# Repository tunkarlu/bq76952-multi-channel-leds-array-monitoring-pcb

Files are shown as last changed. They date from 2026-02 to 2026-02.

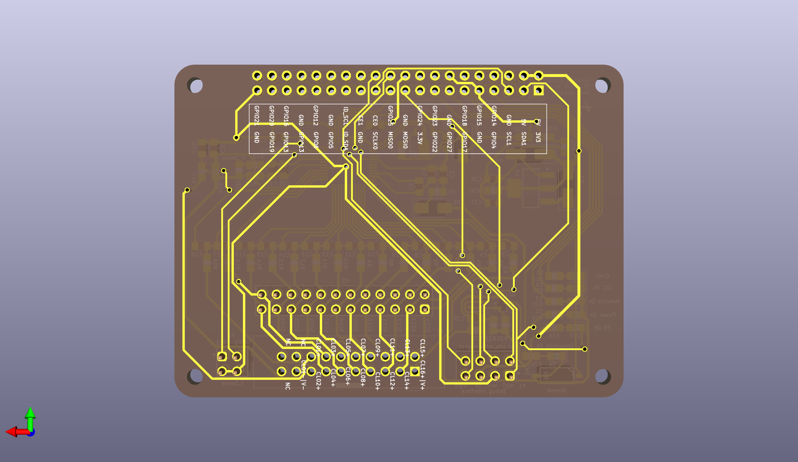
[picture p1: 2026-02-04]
snapshots/BQ76952_uPi_Hat_Bottom.png

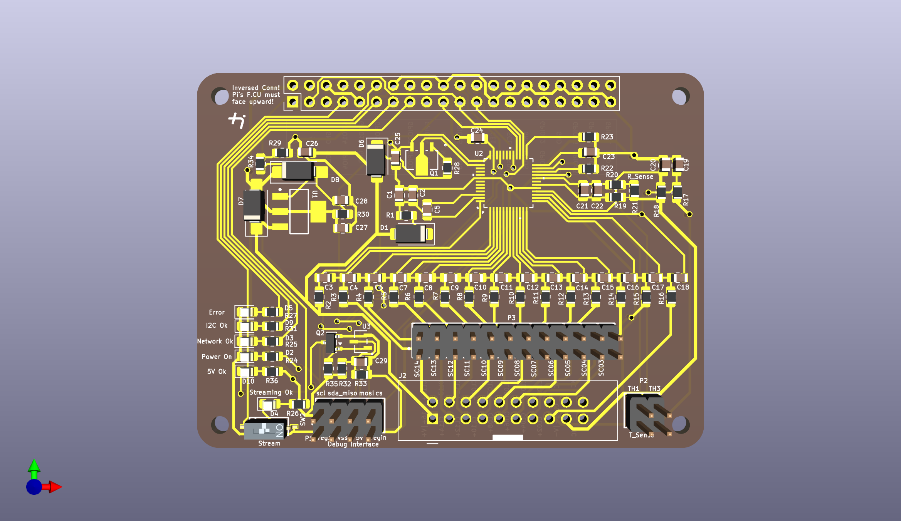
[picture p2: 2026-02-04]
snapshots/BQ76952_uPi_Hat_Top.png

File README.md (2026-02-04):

# BQ76952 Multi-Channel LED Monitoring PCB

## How to Use This Repo
1. Clone or download the project and open `BQ76952_uPi_Hat.kicad_pro` with KiCad 8.x or newer.
2. Use the schematic (`.kicad_sch`) to inspect signal naming, channel scaling, and LM317 regulator settings; propagate changes into the PCB (`.kicad_pcb`) via KiCad's **Update PCB from Schematic** tool.
3. Generate fabrication outputs (Gerbers, drills, pick-and-place, and `BQ76952_uPi_Hat.csv`) when you are ready to order boards or run simulations for your experiments.
4. Document measurement runs and firmware configurations in your own branch to keep bachelor thesis logs aligned with the exact hardware revision.
BQ76952_uPi_Hat_Filled_Top

## Purpose & Scope
This board is the hardware platform for a bachelor thesis focused on predicting high-power LED lifetime and scheduling preventative maintenance. It leverages Texas Instruments' `BQ76952` BMS front-end to acquire per-LED telemetry with up to 32-bit resolution, enabling precise degradation tracking for as many as 16 LEDs (down to 5 by shorting unused inputs). The design is intentionally scalable: multiple boards can share a single Raspberry Pi Zero host via SPI chip-select fan-out or operate independently over I2C.

## Hardware Highlights
- `BQ76952` monitors every LED string, providing ADC accuracy, protection, and internal diagnostics normally reserved for battery stacks.
- External LM317-based LDO supplies the Raspberry Pi Zero directly from the board; an additional comparator supervises the LDO output so a 5 V status indicator confirms the Pi rail is within tolerance.
- Status LEDs expose board health at a glance: chip power-on via the internal LDO, network OK, I2C OK, streaming OK, error flags, and 5 V OK from the comparator stage.
- 2.54 mm pitch Würth 20-pin connector handles the LED array interface with ample current capability and clear pin-1 orientation for field swaps.
- Mini DIP switch enables or disables immediate cloud streaming so field techs can start data uploads without reflashing firmware.
- Debug header breaks out key BQ76952 and Pi Zero signals to simplify firmware bring-up and probing.

## File Structure (Essential Only)
- `BQ76952_uPi_Hat.kicad_pro` – master KiCad project tying schematic, PCB, and fabrication settings together.
- `BQ76952_uPi_Hat.kicad_sch` – complete schematic including LED channels, LM317 LDO, comparator, DIP switch, and interface headers.
- `BQ76952_uPi_Hat.kicad_pcb` – board layout optimized for short sense paths and high-current connector routing.
- `BQ76952_uPi_Hat.csv` – bill of materials exported for sourcing and documentation.
- `BQ76952_uPi_Hat-backups/` – automatically generated KiCad backup snapshots for traceability between thesis milestones.

## Operating Modes & Scalability
- **LED Capacity**: Populate between 5 and 16 channels; unused inputs can be shorted to maintain ADC scaling without redesigning the board.
- **Host Interfaces**: Default communication relies on I2C, but SPI pads and separate slave-select lines allow one microprocessor to orchestrate two boards simultaneously.
- **Streaming Control**: Flip the dedicated DIP switch to trigger the firmware's cloud-streaming routine, useful when demonstrating predictive maintenance dashboards.
- **Resolution**: Each LED measurement path maintains up to 32 bits of resolution through firmware-side accumulation, helping extrapolate lumen depreciation trends.

## Bring-Up & Test Flow
1. Power the board from a current-limited supply, verify the BQ76952 internal LDO brings up the power-on indicator, and ensure the comparator asserts 5 V OK once the LM317 output settles.
2. Attach a Raspberry Pi Zero through the onboard connector, confirm I2C communication, then enable SPI if you plan to chain boards via different slave-select pins.
3. Toggle the DIP switch to start cloud streaming and observe the network and streaming indicators before connecting real LED loads.
4. Connect LED strings incrementally, watching each status LED and reading diagnostic registers to confirm per-channel integrity.
5. Use the debug header to probe GPIOs or update firmware while recording data for the thesis lifetime-prediction models.

## Thesis Context
The design forms the experimental backbone for a bachelor thesis investigating predictive maintenance of high-power LED arrays. It demonstrates how a BMS-grade analog front-end, auxiliary regulation, and human-friendly status cues can be repurposed into a scalable monitoring platform suitable for lab studies and eventual field deployments.

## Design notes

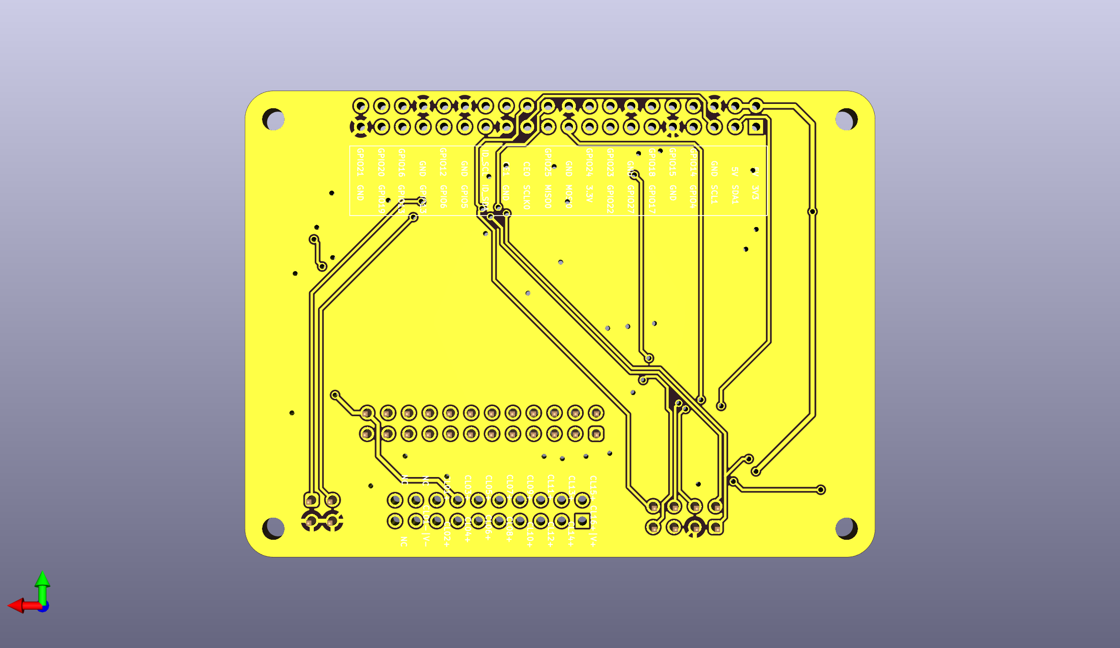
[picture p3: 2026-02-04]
snapshots/BQ76952_uPi_Hat_Filled_Bottom.png

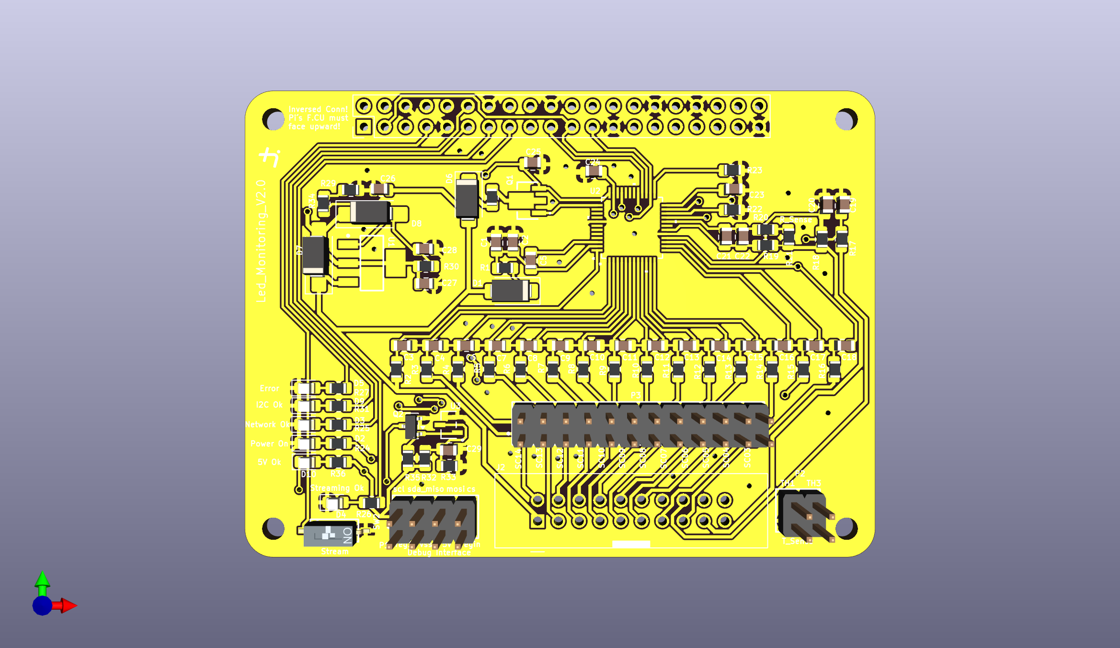
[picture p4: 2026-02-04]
snapshots/BQ76952_uPi_Hat_Filled_Top.png

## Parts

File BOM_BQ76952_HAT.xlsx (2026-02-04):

Main Board
Reference | Value | Datasheet | Footprint | Qty | DNP | Manufacturer Part Number | Manufacturer_Name
C1,C24,C27 | 1uF | ~ | Capacitor_SMD:C_0805_2012Metric,Capacitor_SMD:C_0805_2012Metric_Pad1.18x1.45mm_HandSolder | 3
C2,C21 | 100pF | ~ | Capacitor_SMD:C_0805_2012Metric_Pad1.18x1.45mm_HandSolder | 2
C3,C4,C6,C7,C8,C9,C10,C11,C12,C13,C14,C15,C16,C17,C18,C19,C20 | 220nF | ~ | Capacitor_SMD:C_0805_2012Metric_Pad1.18x1.45mm_HandSolder | 17
C5 | 0.47uF | ~ | Capacitor_SMD:C_0805_2012Metric_Pad1.18x1.45mm_HandSolder | 1
C22,C26 | 0.1uF | ~ | Capacitor_SMD:C_0805_2012Metric,Capacitor_SMD:C_0805_2012Metric_Pad1.18x1.45mm_HandSolder | 2
C23 | 2.2uF | ~ | Capacitor_SMD:C_0805_2012Metric_Pad1.18x1.45mm_HandSolder | 1
C25 | 22nF | ~ | Capacitor_SMD:C_0805_2012Metric_Pad1.18x1.45mm_HandSolder | 1
C28 | 10uF | ~ | Capacitor_SMD:C_0805_2012Metric_Pad1.18x1.45mm_HandSolder | 1
C29 | 100nF | ~ | Capacitor_SMD:C_0805_2012Metric_Pad1.18x1.45mm_HandSolder | 1
D1,D6 | 100V | ~ | Diode_SMD:D_SMA | 2
D2,D3,D4,D5,D9,D10 | LED | ~ | LED_SMD:LED_0805_2012Metric_Pad1.15x1.40mm_HandSolder | 6
D7,D8 | 1N4002 | http://www.vishay.com/docs/88503/1n4001.pdf | Diode_SMD:D_SMA_Handsoldering | 2
J1 | GPIO | ~ | Inverted_PinSocket:PinSocket_2x20_P2.54mm_Vertical_Inverted | 1 |  | 61304021821 | Würth Electronic
J2 | 61202021621 | https://www.we-online.com/en/components/products/datasheet/61202021621?ki | Connector_THT_Würth_BHD:J_Wurth_WR-BHD_61202021621 | 1 |  | 61202021621 | Würth Electronic
P1 | 61300821121 |  | WR_PHD Dual Male:61300821121 | 1 |  | 61300821121 | Würth Electronic
P2 | 61300421121 |  | WR_PHD Dual Male:61300421121 | 1 |  | 61300421121 | Würth Electronic
P3 | 61302421121 |  | WR_PHD Dual Male:61302421121 | 1 |  | 61302421121 | Würth Electronic
Q1 | NPN | https://ngspice.sourceforge.io/docs/ngspice-html-manual/manual.xhtml#cha_BJTs | FCX495TA:SOT89_DIO | 1 |  | FCX495TA
Q2 | 2N7002 | https://www.onsemi.com/pub/Collateral/NDS7002A-D.PDF | Package_TO_SOT_SMD:SOT-23 | 1 |  | 2N7002 | Onsemi
R1,R19,R20 | 100 | ~ | Resistor_SMD:R_0805_2012Metric_Pad1.20x1.40mm_HandSolder | 3
R2,R3,R4,R5,R6,R7,R8,R9,R10,R11,R12,R13,R14,R15,R16,R17,R18 | 20 | ~ | Resistor_SMD:R_0805_2012Metric_Pad1.20x1.40mm_HandSolder | 17
R21 | 0.001 | ~ | Resistor_SMD:R_0805_2012Metric_Pad1.20x1.40mm_HandSolder | 1
R22,R33,R35 | 10k | ~ | Resistor_SMD:R_0805_2012Metric_Pad1.20x1.40mm_HandSolder | 3
R23 | 1k | ~ | Resistor_SMD:R_0805_2012Metric_Pad1.20x1.40mm_HandSolder | 1
R24,R25,R26,R27,R31,R36 | R | ~ | Resistor_SMD:R_0805_2012Metric_Pad1.20x1.40mm_HandSolder | 6
R28 | 300 | ~ | Resistor_SMD:R_0805_2012Metric_Pad1.20x1.40mm_HandSolder | 1
R29 | 680 | ~ | Resistor_SMD:R_0805_2012Metric_Pad1.20x1.40mm_HandSolder | 1
R30 | 240 | ~ | Resistor_SMD:R_0805_2012Metric_Pad1.20x1.40mm_HandSolder | 1
R32 | 1.5k | ~ | Resistor_SMD:R_0805_2012Metric_Pad1.20x1.40mm_HandSolder | 1
R34 | 33 | ~ | Resistor_SMD:R_0805_2012Metric_Pad1.20x1.40mm_HandSolder | 1
SW2 | 416131160801 | ~ | WS-DISV:416131160801 | 1 |  | 416131160801 | Würth Electronic
U1 | LM317DCY | https://www.ti.com/lit/gpn/lm317 | LM317DCY:DCY0004A_N | 1 |  | LM317DCY | TI
U2 | PBQ76952PFBT | https://www.ti.com/lit/gpn/bq76952 | BQ769x2:PFB48_TEX | 1 |  | BQ76952 | TI
U3 | STM1061N38WX6F | https://www.st.com/resource/en/datasheet/stm1061.pdf | STM1061N38WX6F:SOT-23_STM | 1 |  | STM1061N38WX6F | ST
Mating Connector
Pi Pin Header |  |  |  | 1 |  | 61304021121 | Würth Electronic
WE BHD 20 pins cable side |  |  |  | 2 |  | 61202023021 | Würth Electronic
Ribbon cable 20 pins |  |  |  | 1 |  | 63912015521 or 63912015521CAB | Würth Electronic
Breakout Board
Reference | Qty | Value | DNP | Exclude from BOM | Exclude from Board | Footprint | Datasheet | Manufacturer_Name | Manufacturer_Part_Number
J1,J3 | 2 | 61202021621 |  |  |  | Connector_THT_Würth_BHD:J_Wurth_WR-BHD_61202021621 | https://www.we-online.com/en/components/products/datasheet/61202021621?ki | Würth Electronic | 61202021621
J2,J4,J5,J6,J7,J8,J9,J10 | 8 | 20021321-00006C4LF |  |  |  | Amphenol:2002132100006C4LF | https://cdn.amphenol-cs.com/media/wysiwyg/files/documentation/datasheet/boardwiretoboard/bwb_minitek127_btb.pdf | Amphenol Communications Solutions | 20021321-00006C4LF

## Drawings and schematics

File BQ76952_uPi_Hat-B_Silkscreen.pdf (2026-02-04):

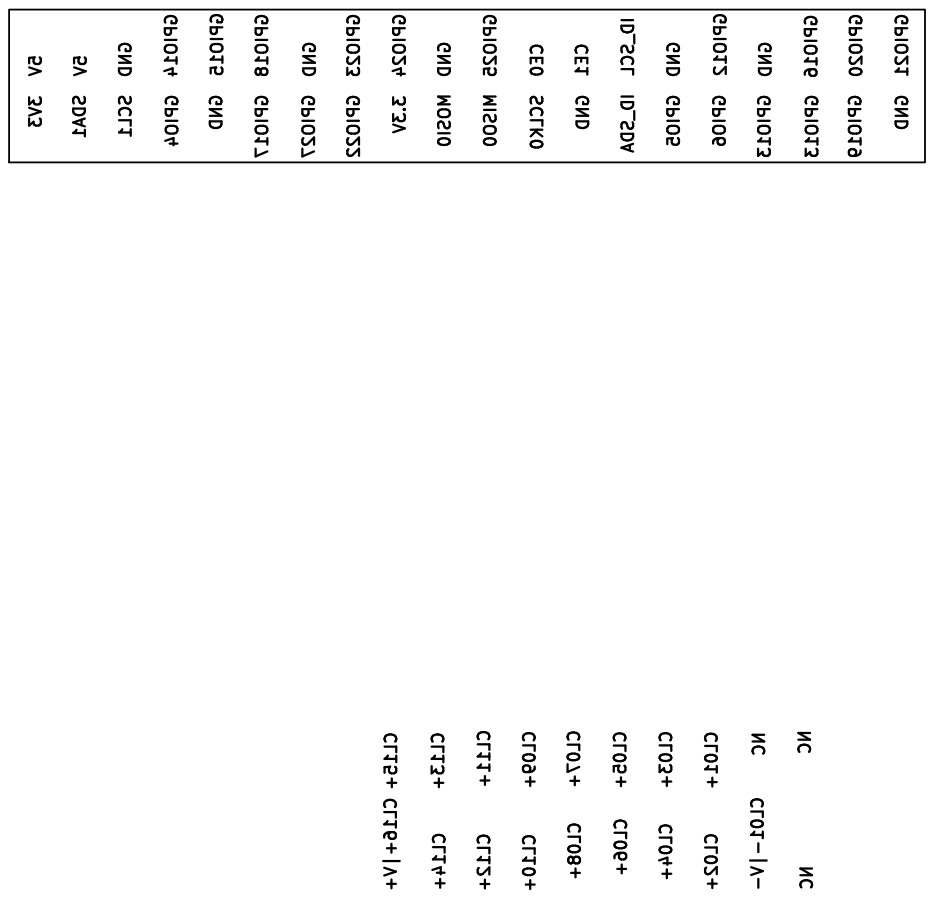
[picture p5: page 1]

CL03+ NC NC CL02+ CL16+|V+ CL01-|V- CL07+ CL14+ CL12+ CL15+ CL09+ CL06+ CL11+ NC CL10+ CL05+ CL08+ CL04+ CL13+ CL01+ SDA1 SCL1 GPIO22 3.3V MOSI0 MISO0 GPIO5 GPIO18 GPIO23 GPIO25 ID_SCL GPIO20 3V3 GND GPIO165V ID_SDA CE0 GPIO13 GPIO19 GPIO12 GPIO27 GND GPIO14 GPIO21 GPIO4 SCLK0 GND CE1 GND GPIO17 GPIO6 5V GND GPIO15 GPIO24 GPIO13 GND GND GND

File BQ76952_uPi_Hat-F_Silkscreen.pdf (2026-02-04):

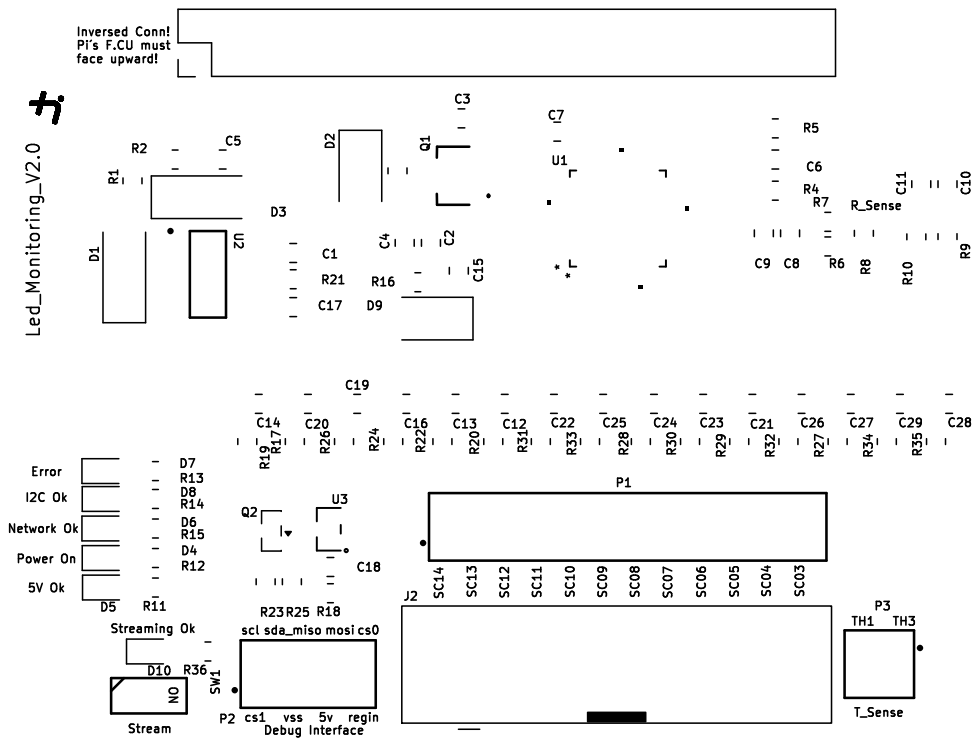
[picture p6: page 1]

Inversed Conn! þÿPi´s F.CU must
face upward! Led_Monitoring_V2.0

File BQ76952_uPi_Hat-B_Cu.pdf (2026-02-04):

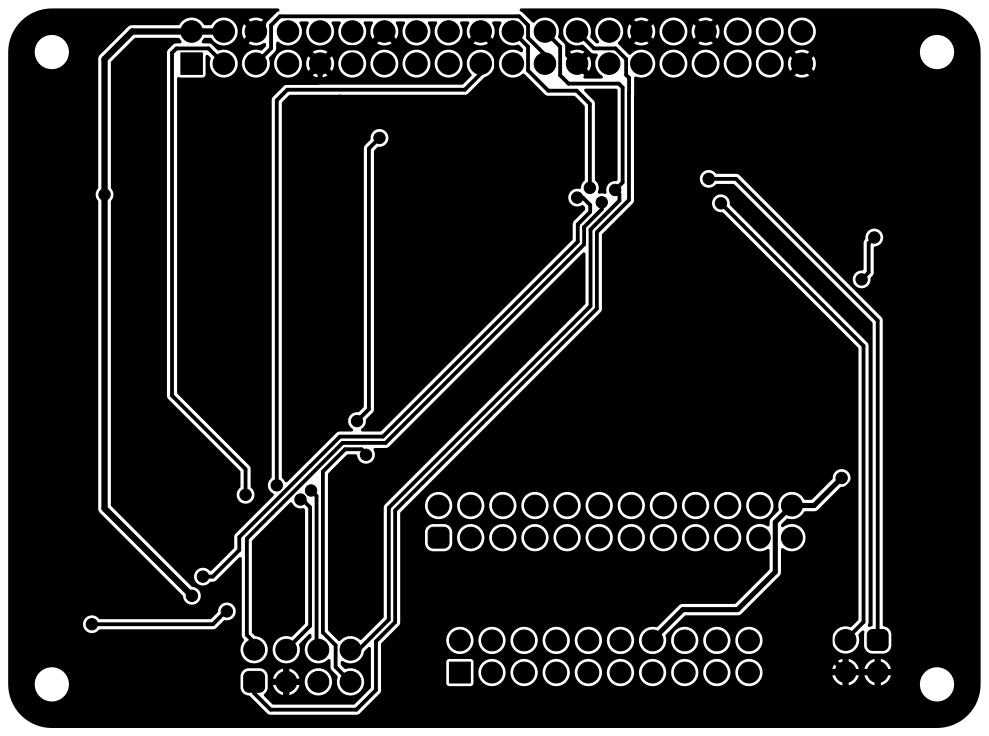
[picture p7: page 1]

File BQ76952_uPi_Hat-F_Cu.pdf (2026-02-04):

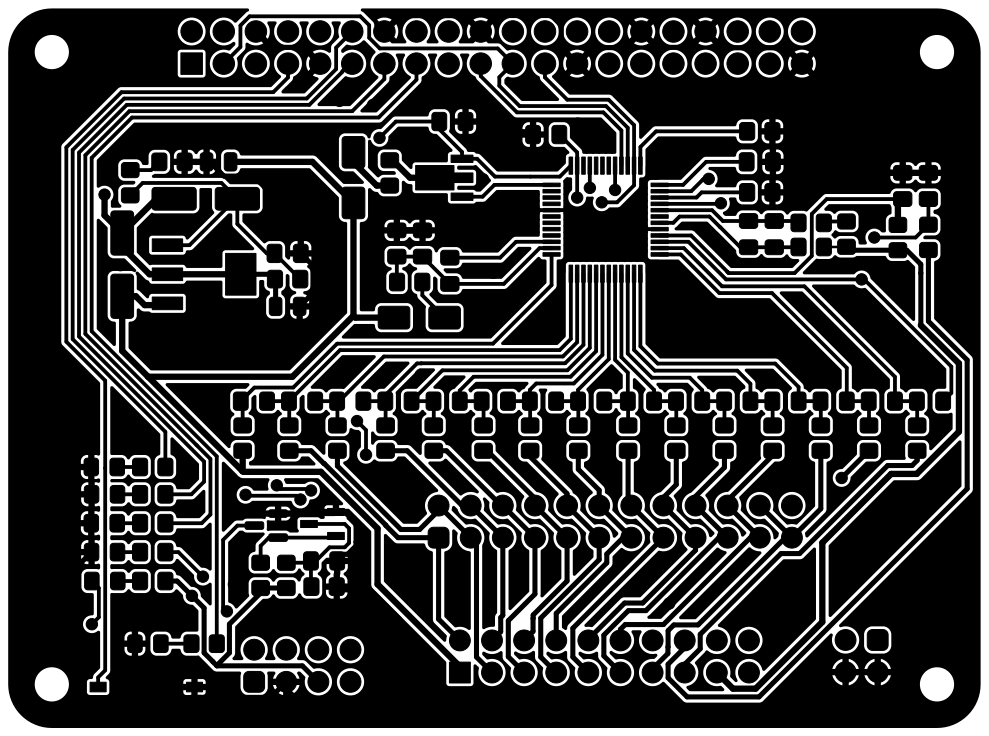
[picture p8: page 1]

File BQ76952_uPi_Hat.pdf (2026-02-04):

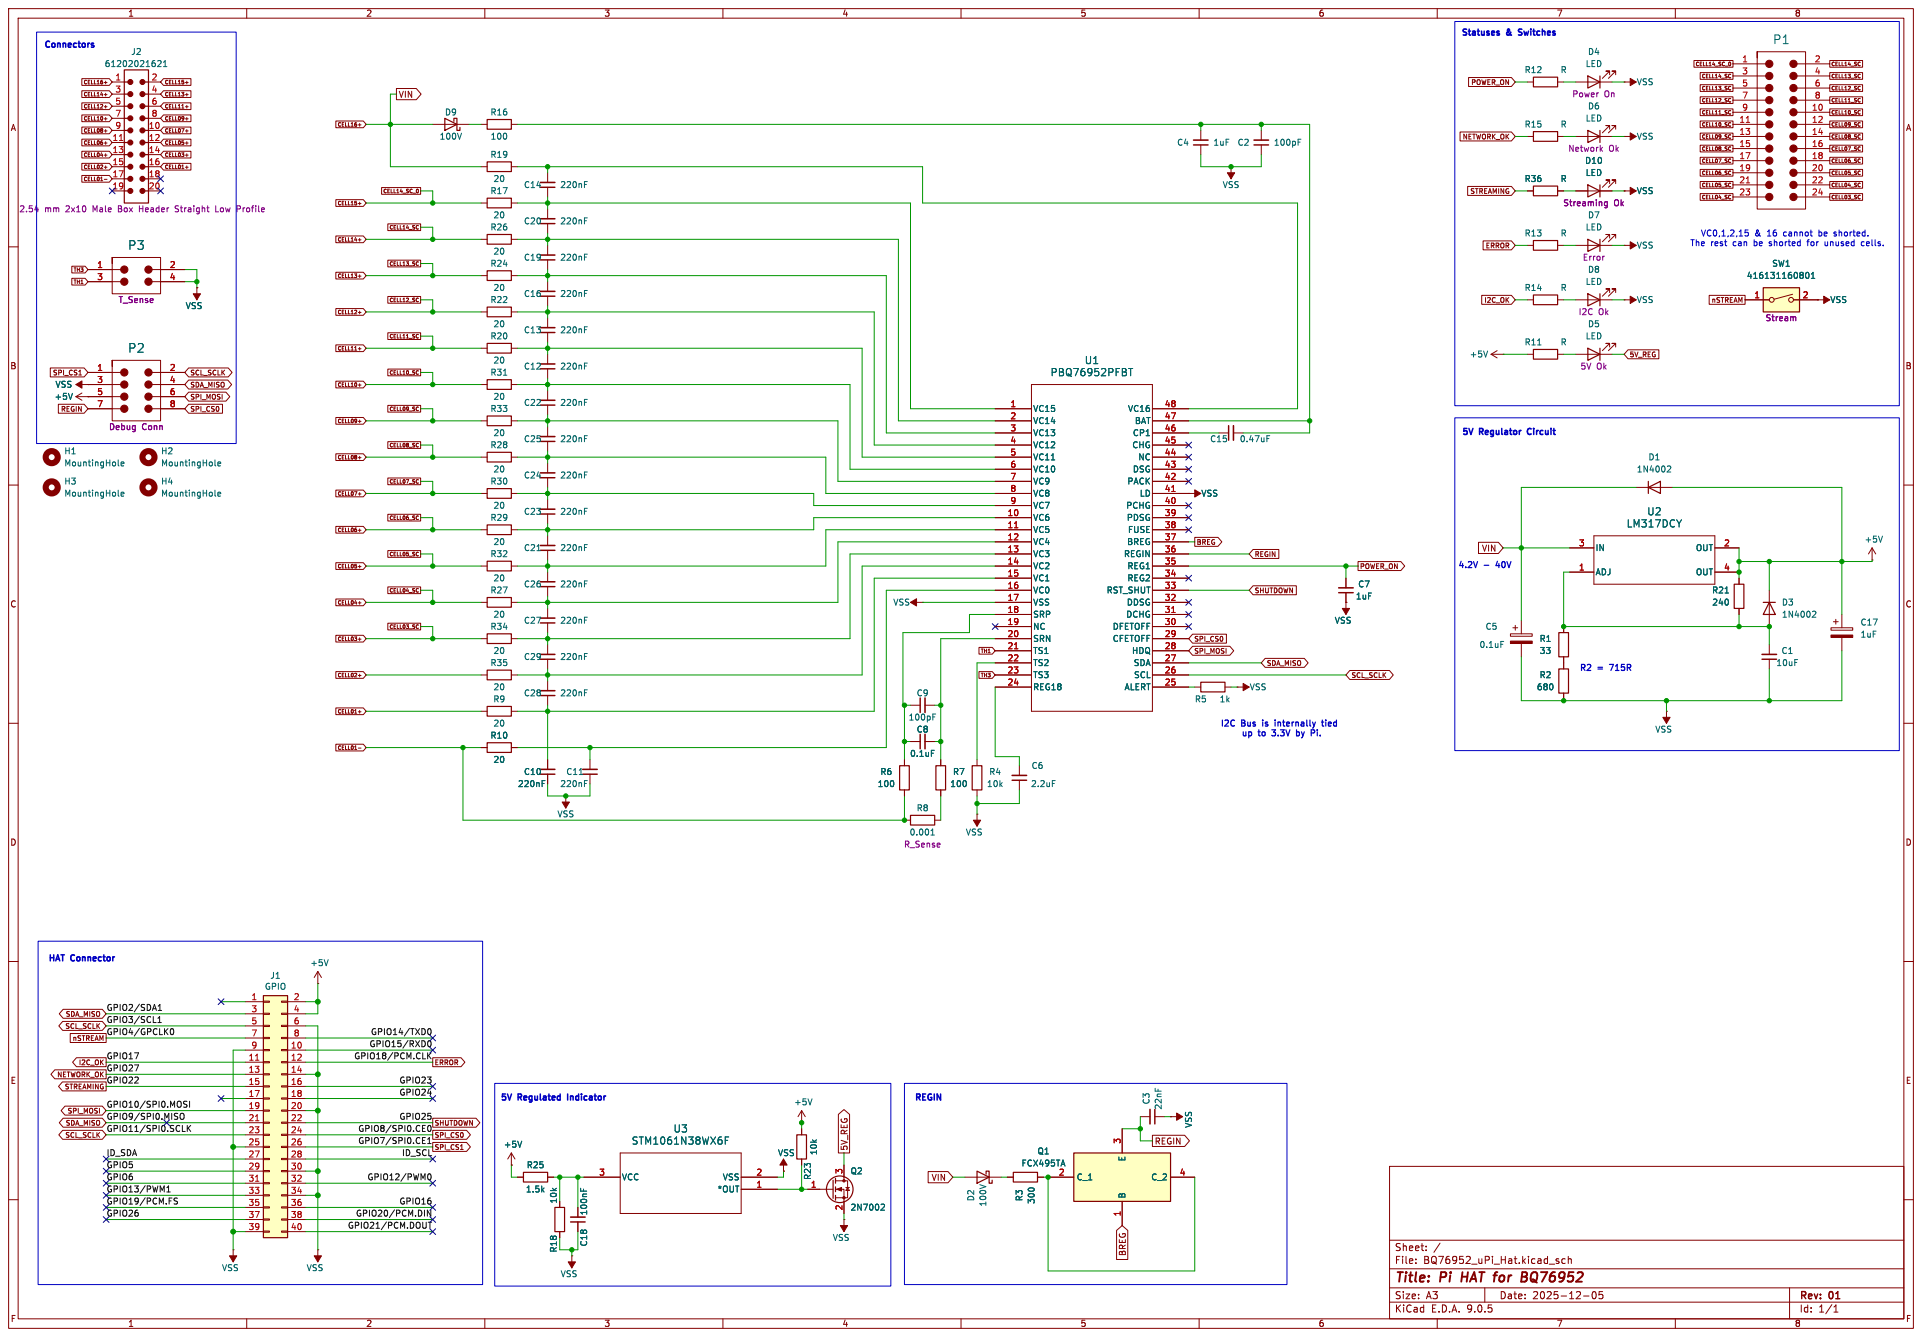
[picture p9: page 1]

Id: 1/1 Title: Pi HAT for BQ76952

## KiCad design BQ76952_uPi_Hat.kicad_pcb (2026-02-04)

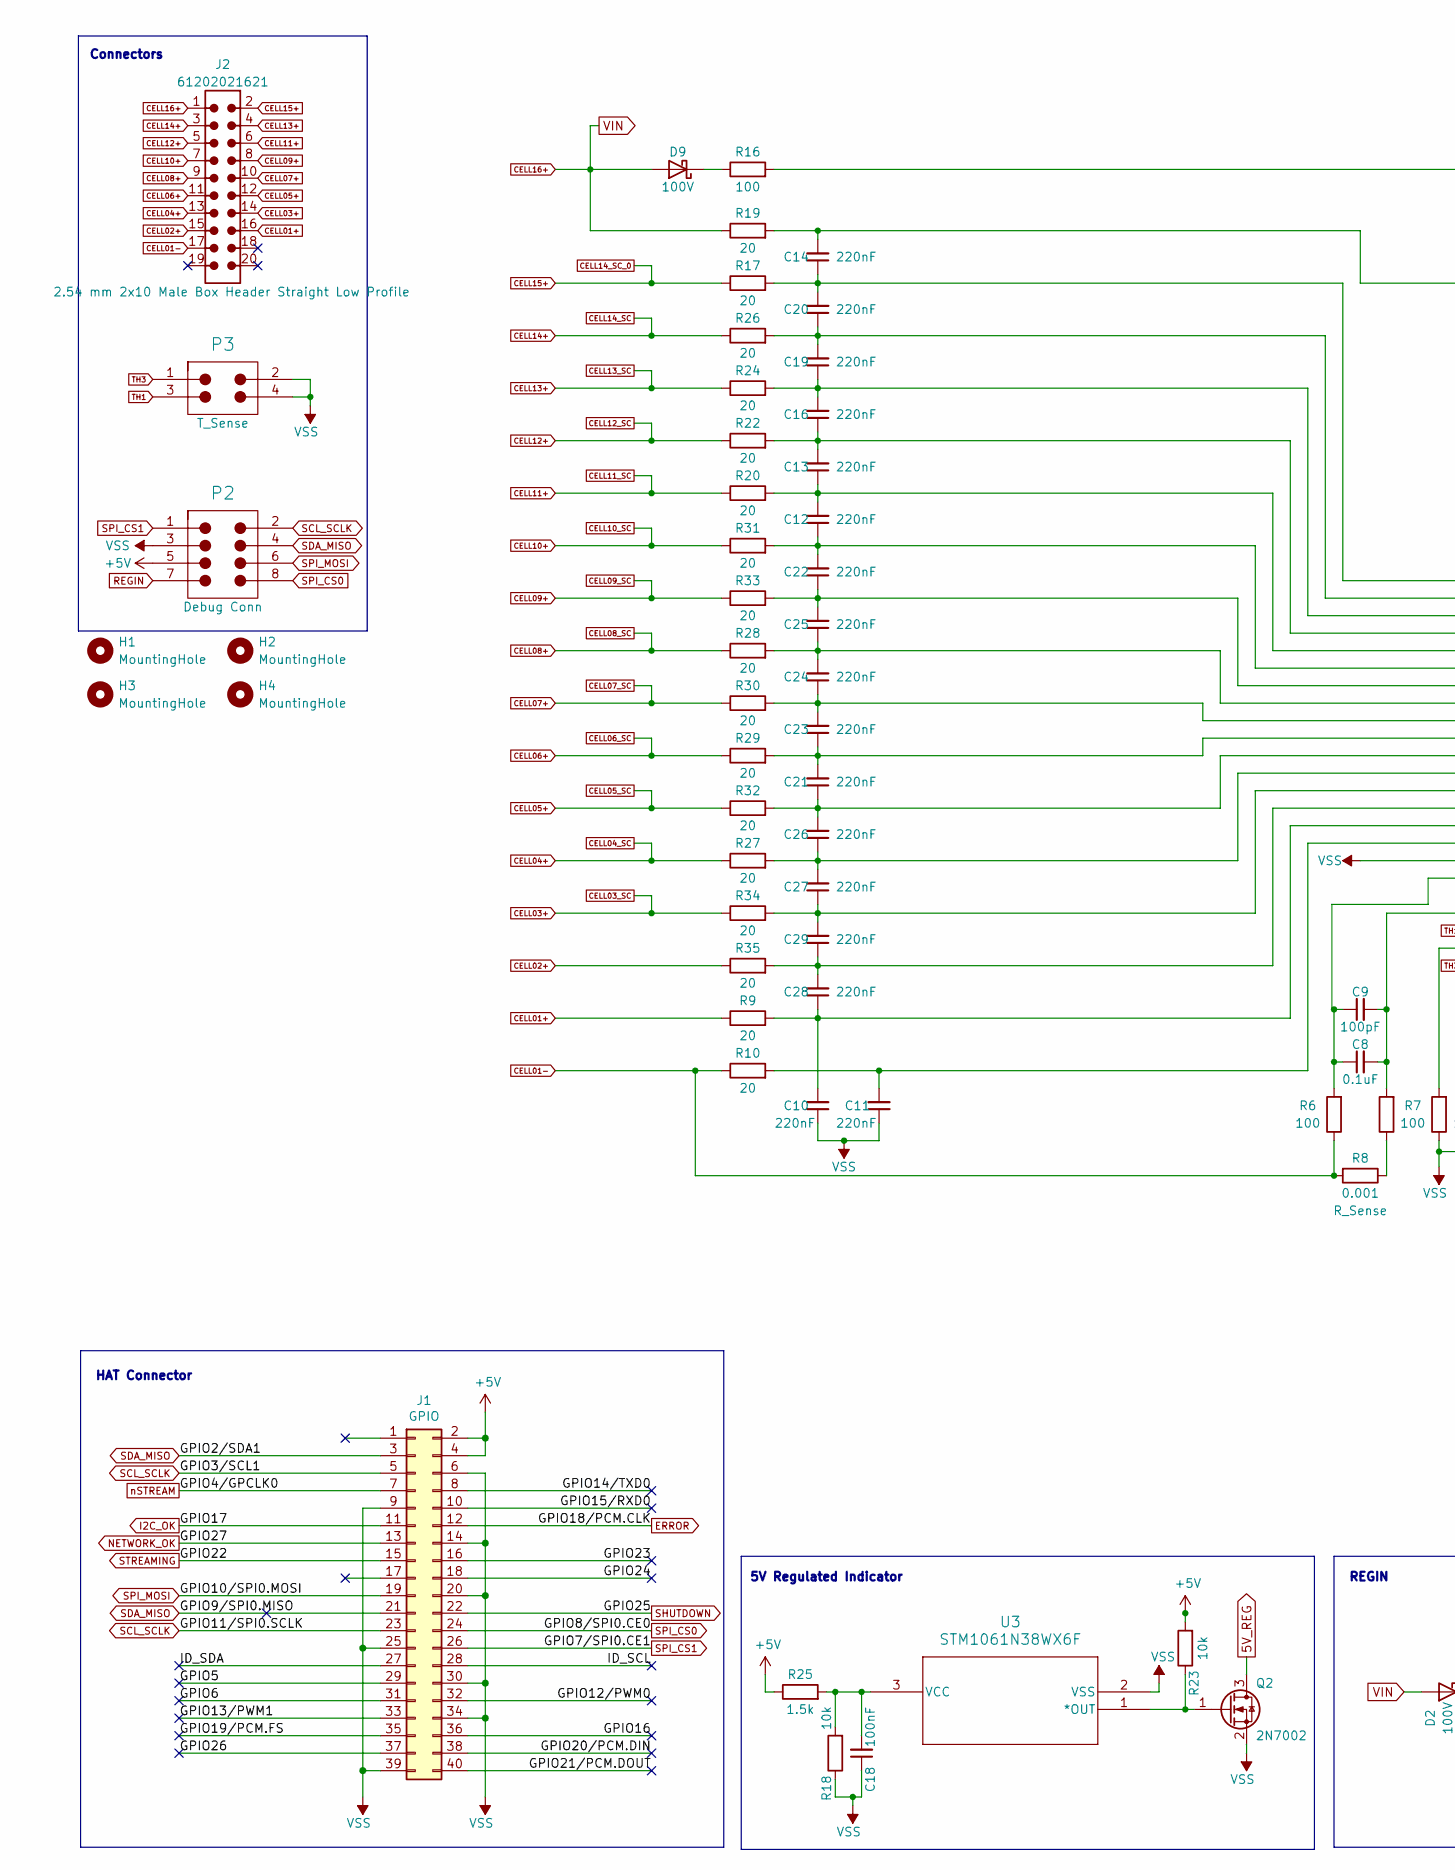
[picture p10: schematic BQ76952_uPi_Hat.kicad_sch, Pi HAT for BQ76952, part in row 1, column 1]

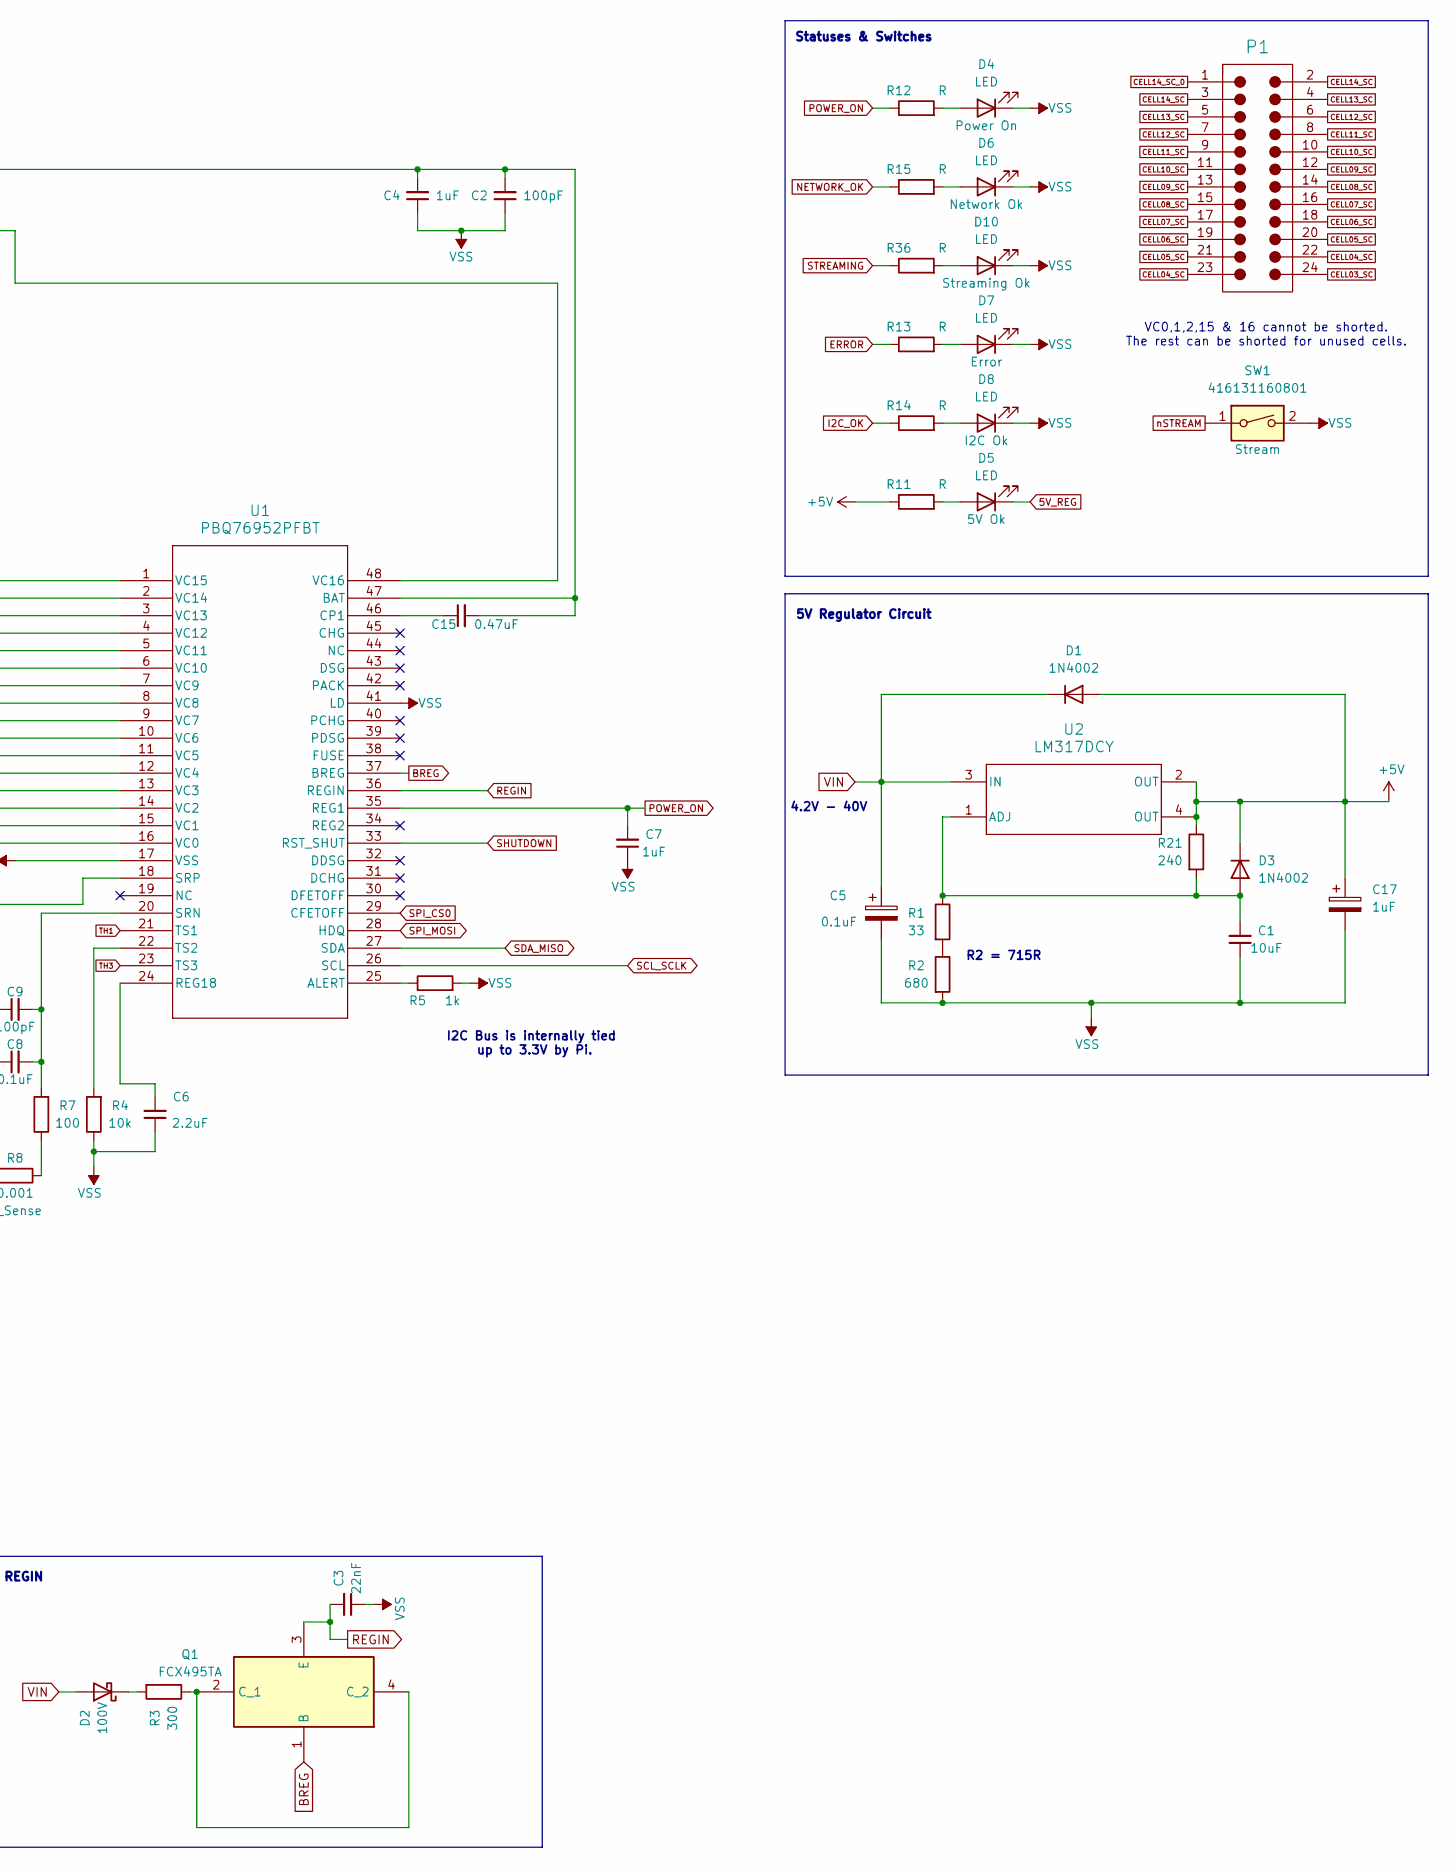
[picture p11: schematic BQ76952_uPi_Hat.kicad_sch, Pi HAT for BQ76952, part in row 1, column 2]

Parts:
C1: 10uF; C_0805_2012Metric_Pad1.18x1.45mm_HandSolder
C2, C9: 100pF; C_0805_2012Metric_Pad1.18x1.45mm_HandSolder
C3: 22nF; C_0805_2012Metric_Pad1.18x1.45mm_HandSolder
C4, C7: 1uF; C_0805_2012Metric_Pad1.18x1.45mm_HandSolder
C5: 0.1uF; C_0805_2012Metric
C6: 2.2uF; C_0805_2012Metric_Pad1.18x1.45mm_HandSolder
C8: 0.1uF; C_0805_2012Metric_Pad1.18x1.45mm_HandSolder
C10, C11, C12, C13, C14, C16, C19, C20, C21, C22, C23, C24, C25, C26, C27, C28, C29: 220nF; C_0805_2012Metric_Pad1.18x1.45mm_HandSolder
C15: 0.47uF; C_0805_2012Metric_Pad1.18x1.45mm_HandSolder
C17: 1uF; C_0805_2012Metric
C18: 100nF; C_0805_2012Metric_Pad1.18x1.45mm_HandSolder
D1, D3: 1N4002; D_SMA_Handsoldering
D2, D9: 100V; D_SMA
D4, D5, D6, D7, D8, D10: LED; LED_0805_2012Metric_Pad1.15x1.40mm_HandSolder
H1, H2, H3, H4: MountingHole; MountingHole_2.7mm_M2.5_DIN965
J1: GPIO; PinSocket_2x20_P2.54mm_Vertical_Inverted
J2: 61202021621; J_Wurth_WR-BHD_61202021621
P1: 61302421121; Working Voltage 250V; Withstanding Voltage 500V; Manufacturer Part Number 61302421121
P2: 61300821121; Working Voltage 250V; Withstanding Voltage 500V; Manufacturer Part Number 61300821121
P3: 61300421121; Working Voltage 250V; Withstanding Voltage 500V; Manufacturer Part Number 61300421121
Q1: FCX495TA; FCX495QTA; Mouser Part Number 522-FCX495TA
Q2: 2N7002; SOT-23
R1: 33; R_0805_2012Metric_Pad1.20x1.40mm_HandSolder
R2: 680; R_0805_2012Metric_Pad1.20x1.40mm_HandSolder
R3: 300; R_0805_2012Metric_Pad1.20x1.40mm_HandSolder
R4, R18, R23: 10k; R_0805_2012Metric_Pad1.20x1.40mm_HandSolder
R5: 1k; R_0805_2012Metric_Pad1.20x1.40mm_HandSolder
R6, R7, R16: 100; R_0805_2012Metric_Pad1.20x1.40mm_HandSolder
R8: 0.001; R_0805_2012Metric_Pad1.20x1.40mm_HandSolder
R9, R10, R17, R19, R20, R22, R24, R26, R27, R28, R29, R30, R31, R32, R33, R34, R35: 20; R_0805_2012Metric_Pad1.20x1.40mm_HandSolder
R11, R12, R13, R14, R15, R36: R; R_0805_2012Metric_Pad1.20x1.40mm_HandSolder
R21: 240; R_0805_2012Metric_Pad1.20x1.40mm_HandSolder
R25: 1.5k; R_0805_2012Metric_Pad1.20x1.40mm_HandSolder
SW1: 416131160801
U1: PBQ76952PFBT; PFB48_TEX
U2: LM317DCY; DCY0004A_N
U3: STM1061N38WX6F; SOT-23_STM

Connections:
5V_REG: D5.1 (K), Q2.3 (D)
+5V: C17.1, D1.2 (A), D3.1 (K), J1.2, J1.4, P2.5, R11.1, R21.1, R23.2, R25.1, U2.2 (OUT), U2.4 (OUT)
/GPIO5: J1.29
/GPIO6: J1.31
/GPIO12/PWM0: J1.32
/GPIO13/PWM1: J1.33
/GPIO14/TXD0: J1.8
/GPIO15/RXD0: J1.10
/GPIO16: J1.36
/GPIO19/PCM.FS: J1.35
/GPIO20/PCM.DIN: J1.38
/GPIO21/PCM.DOUT: J1.40
/GPIO23: J1.16
/GPIO24: J1.18
/GPIO26: J1.37
/ID_SCL: J1.28
/ID_SDA: J1.27
BREG: Q1.1 (B), U1.37 (BREG)
CELL01+: J2.16, R9.1
CELL01-: J2.17, R6.1, R8.2, R10.1
CELL02+: J2.15, R35.1
CELL03+: J2.14, P1.24, R34.1
CELL04+: J2.13, P1.22, P1.23, R27.1
CELL05+: J2.12, P1.20, P1.21, R32.1
CELL06+: J2.11, P1.18, P1.19, R29.1
CELL07+: J2.10, P1.16, P1.17, R30.1
CELL08+: J2.9, P1.14, P1.15, R28.1
CELL09+: J2.8, P1.12, P1.13, R33.1
CELL10+: J2.7, P1.10, P1.11, R31.1
CELL11+: J2.6, P1.8, P1.9, R20.1
CELL12+: J2.5, P1.6, P1.7, R22.1
CELL13+: J2.4, P1.4, P1.5, R24.1
CELL14+: J2.3, P1.2, P1.3, R26.1
CELL14_SC_0: J2.2, P1.1, R17.1
CELL16+: C5.1, D1.1 (K), D2.2 (A), D9.2 (A), J2.1, R19.1, U2.3 (IN)
ERROR: J1.12, R13.1
I2C_OK: J1.11, R14.1
NETWORK_OK: J1.13, R15.1
unnamed: D9.1 (K), R16.1
unnamed: D4.2 (A), R12.2
unnamed: D6.2 (A), R15.2
unnamed: D10.2 (A), R36.2
unnamed: D7.2 (A), R13.2
unnamed: D2.1 (K), R3.2
unnamed: C1.2, D3.2 (A), R1.1, R21.2, U2.1 (ADJ)
unnamed: D8.2 (A), R14.2
unnamed: D5.2 (A), R11.2
unnamed: Q1.2 (C_1), Q1.4 (C_2), R3.1
unnamed: Q2.1 (G), R23.1, U3.1 (*OUT)
unnamed: R7.1, R8.1
unnamed: R1.2, R2.1
unnamed: R5.1, U1.25 (ALERT)
unnamed: C2.2, C4.2, C15.2, R16.2, U1.47 (BAT)
unnamed: C15.1, U1.46 (CP1)
unnamed: C6.2, U1.24 (REG18)
unnamed: C8.2, C9.2, R7.2, U1.20 (SRN)
unnamed: C8.1, C9.1, R6.2, U1.18 (SRP)
unnamed: R4.2, U1.22 (TS2)
unnamed: C11.2, R10.2, U1.16 (VC0)
unnamed: C10.2, C28.1, R9.2, U1.15 (VC1)
unnamed: C28.2, C29.1, R35.2, U1.14 (VC2)
unnamed: C27.1, C29.2, R34.2, U1.13 (VC3)
unnamed: C26.1, C27.2, R27.2, U1.12 (VC4)
unnamed: C21.1, C26.2, R32.2, U1.11 (VC5)
unnamed: C21.2, C23.1, R29.2, U1.10 (VC6)
unnamed: C23.2, C24.1, R30.2, U1.9 (VC7)
unnamed: C24.2, C25.1, R28.2, U1.8 (VC8)
unnamed: C22.1, C25.2, R33.2, U1.7 (VC9)
unnamed: C12.1, C22.2, R31.2, U1.6 (VC10)
unnamed: C12.2, C13.1, R20.2, U1.5 (VC11)
unnamed: C13.2, C16.1, R22.2, U1.4 (VC12)
unnamed: C16.2, C19.1, R24.2, U1.3 (VC13)
unnamed: C19.2, C20.1, R26.2, U1.2 (VC14)
unnamed: C14.1, C20.2, R17.2, U1.1 (VC15)
unnamed: C14.2, R19.2, U1.48 (VC16)
unnamed: C18.2, R18.2, R25.2, U3.3 (VCC)
POWER_ON: C7.2, R12.1, U1.35 (REG1)
REGIN: C3.2, P2.7, Q1.3 (E), U1.36 (REGIN)
SCL_SCLK: J1.5, J1.23, P2.2, U1.26 (SCL)
SDA_MISO: J1.3, J1.21, P2.4, U1.27 (SDA)
SHUTDOWN: J1.22, U1.33 (RST_SHUT)
SPI_CS0: J1.24, P2.8, U1.29 (CFETOFF)
SPI_CS1: J1.26, P2.1
SPI_MOSI: J1.19, P2.6, U1.28 (HDQ)
STREAMING: J1.15, R36.1
TH1: P3.3, U1.21 (TS1)
TH3: P3.1, U1.23 (TS3)
VSS: C1.1, C2.1, C3.1, C4.1, C5.2, C6.1, C7.1, C10.1, C11.1, C17.2, C18.1, D4.1 (K), D6.1 (K), D7.1 (K), D8.1 (K), D10.1 (K), J1.6, J1.9, J1.14, J1.20, J1.25, J1.30, J1.34, J1.39, P2.3, P3.2, P3.4, Q2.2 (S), R2.2, R4.1, R5.2, R18.1, SW1.2, U1.17 (VSS), U1.41 (LD), U3.2 (VSS)
nSTREAM: J1.7, SW1.1

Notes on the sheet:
4.2V - 40V
HAT Connector
R2 = 715R
5V Regulator Circuit
Connectors
5V Regulated Indicator
I2C Bus is internally tied up to 3.3V by Pi.
Statuses & Switches
VC0,1,2,15 & 16 cannot be shorted. The rest can be shorted for unused cells.
REGIN

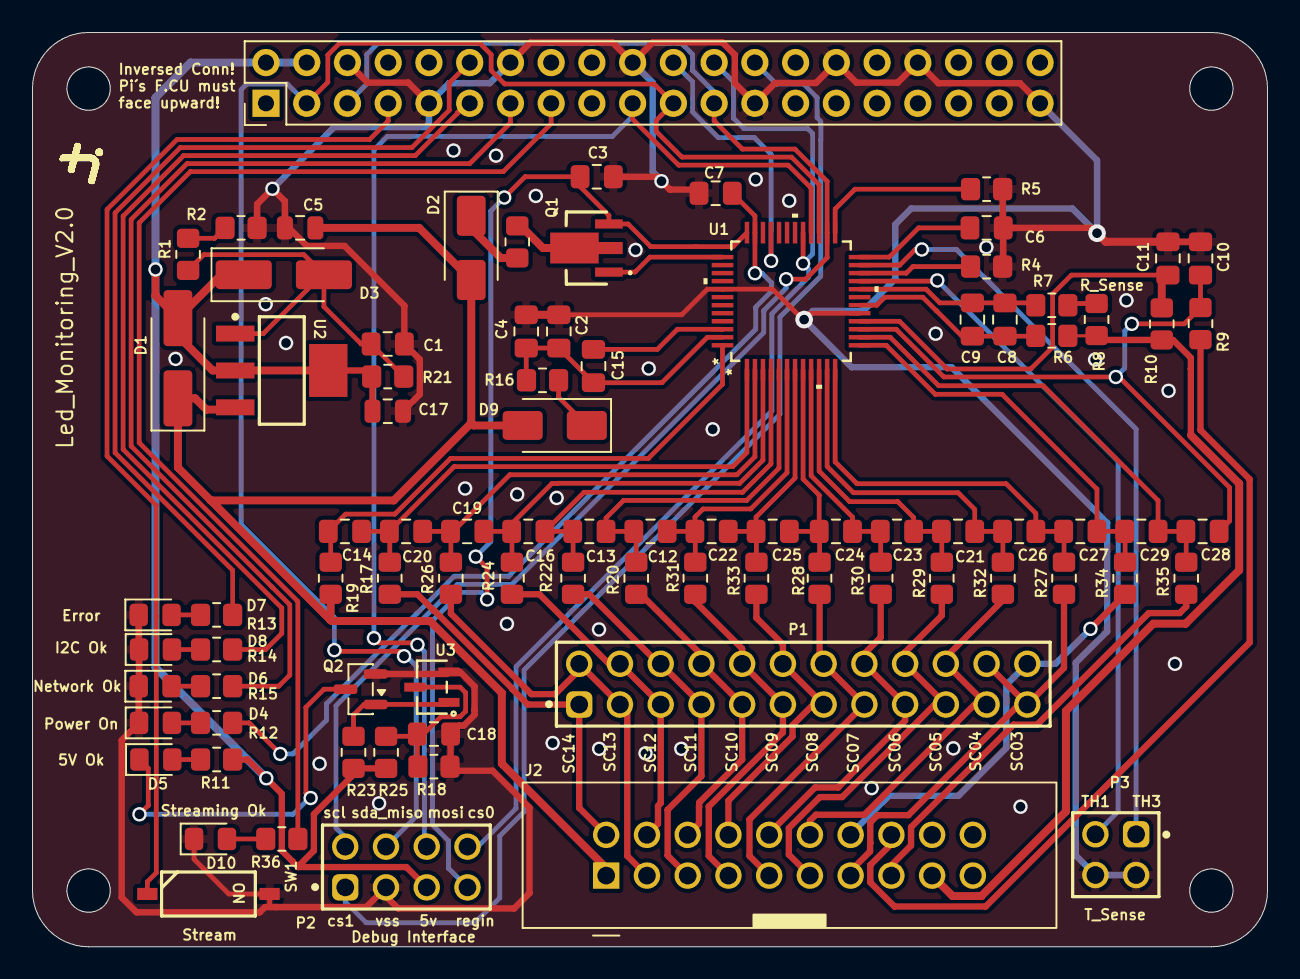
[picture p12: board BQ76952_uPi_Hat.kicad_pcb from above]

Board: 2 copper layers, 77.0 x 57.0 mm, 90 parts (0 on the bottom side), 74 nets.
